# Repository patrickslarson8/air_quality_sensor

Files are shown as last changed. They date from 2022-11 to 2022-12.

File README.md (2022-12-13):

# Air Quality Sensor

A small air quality sensor that measures various 
aspects and logs them for later analysis.
Measures: VOC, C02, temperature, PM2.5, and humidity

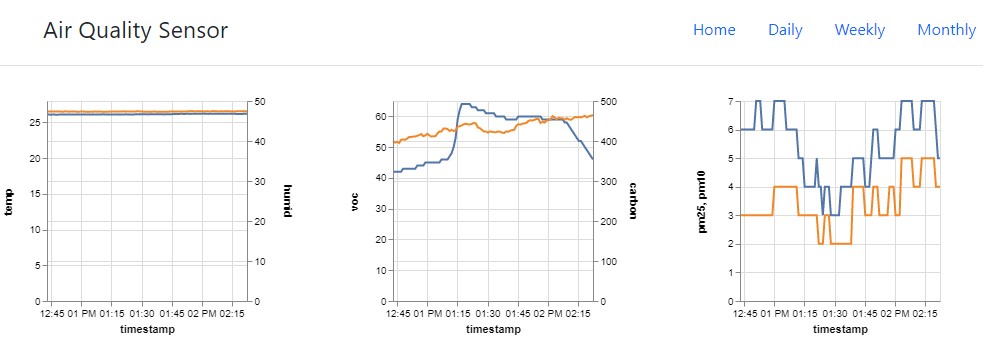
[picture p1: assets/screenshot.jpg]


## Hardware

Raspberry Pi
Adafruit SGP40 (https://learn.adafruit.com/adafruit-sgp40/python-circuitpython)  
Adafruit SCD-40 (https://learn.adafruit.com/adafruit-scd-40-and-scd-41/python-circuitpython)  
Adafruit PM 2.5 Sensor (https://learn.adafruit.com/pm25-air-quality-sensor)  

## How to use

### Wiring

- Notice that we are using the voltage regulator of the SGP40 to power the SCD40. This is because there is limited current supply from the Raspberry Pi and the RPi is notorious for weird bugs when underpowered.
- Additionally we need two wires that are split (purple and brown) so that both SGP40 & SCD40 can share the RPi i2c pins.
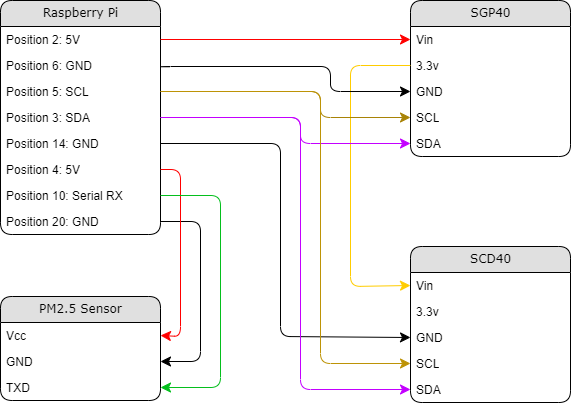
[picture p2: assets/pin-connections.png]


### Coding

1. Download repo

~~~bash
cd ~
git clone https://github.com/patrickslarson8/air_quality_sensor.git
~~~

2. Install requirements on system

~~~bash
cd air_quality_sensor
sudo apt-get install sqlite3 python3-pip libatlas-base-dev
~~~

3. Install python packages

~~~bash
sudo pip3 install -r requirements.txt
~~~

4. Create SQLite database

~~~bash
cd air-quality-service
sqlite3 database.db
sqlite> BEGIN;
sqlite> CREATE TABLE sensor_table (timestamp DATETIME, temp NUMERIC, humid NUMERIC, carbon NUMERIC, voc NUMERIC, pm10 NUMERIC, pm25 NUMERIC);
sqlite> CREATE TABLE note_table (timestamp DATETIME, note text);
sqlite> COMMIT;
~~~

5. Configure air_quality.py and webserver.py to autostart

- Open air_quality.service and web_server.service in a text editor and ensure the two locations for ExecStart point to your python interpretor and air_quality.py locations
- Copy air_quality.service to /lib/systemd/system/
- Add the correct permissions to the service file

~~~bash
sudo cp air_quality.service /lib/systemd/system/air_quality.service
sudo chmod 644 /lib/systemd/system/air_quality.service
sudo cp web_server.service /lib/systemd/system/web_server.service
sudo chmod 644 /lib/systemd/system/web_server.service
~~~

- Configure service to start

~~~bash
sudo systemctl daemon-reload
sudo systemctl enable air_quality.service
sudo systemctl enable web_server.service
sudo reboot
~~~

6. Schedule automatic reboot
~~~bash
sudo crontab -e
~~~
- Select the first option, nano
- Add the following at the end of the file
~~~bash
0 6 * * * /sbin/shutdown -r now
~~~
- Save the file by pressing ctrl+x then y

## Todo list

1. Add notes input to web page
2. Make air_quality service fault tolerant
  - Sensor Disconnect
  - Database non-existance
3. Fix time drift for polling (doesn't account for time taken to execute)

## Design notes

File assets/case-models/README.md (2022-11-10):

# Physical Enclosure Files

## How to use

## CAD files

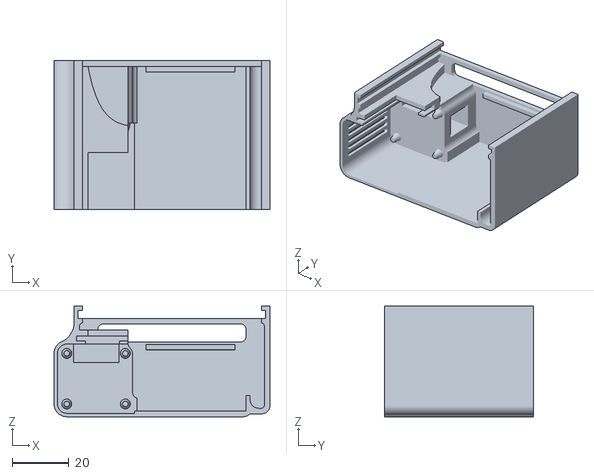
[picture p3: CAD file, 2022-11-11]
assets/case-models/Top Case.stl
76.0 x 52.3 x 38.9

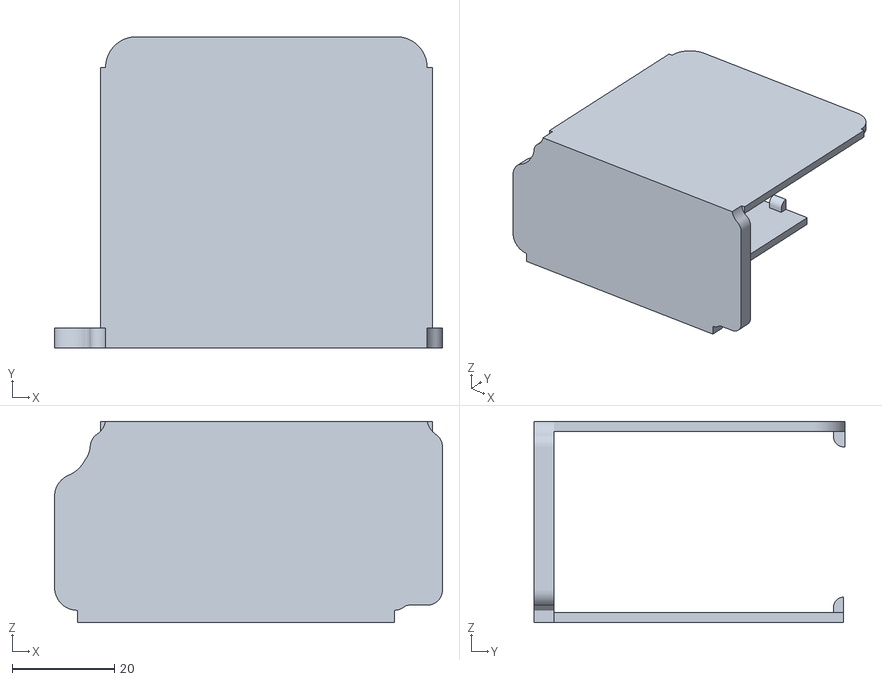
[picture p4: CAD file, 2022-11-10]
assets/case-models/Outer Lid.stl
76.0 x 61.0 x 39.4

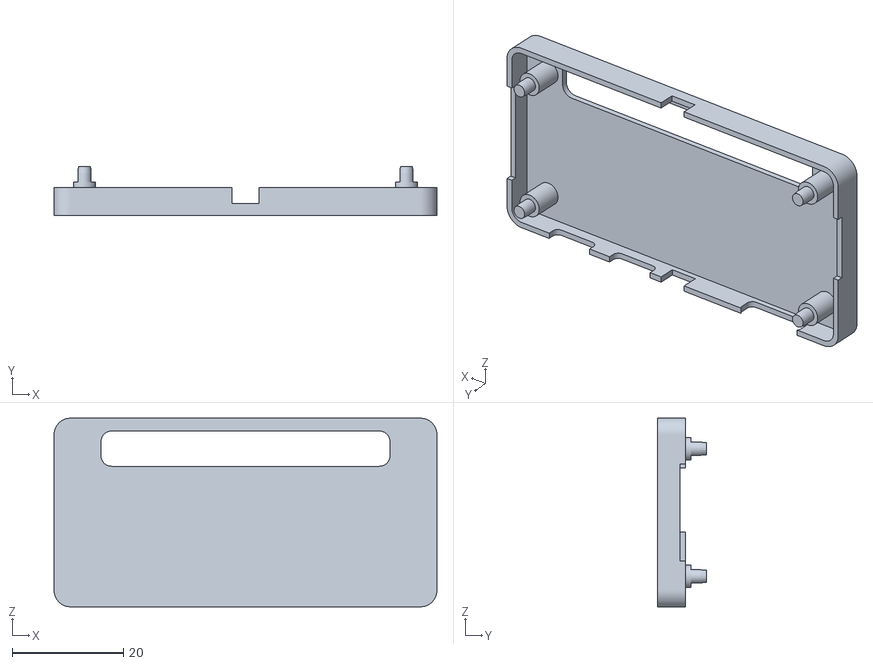
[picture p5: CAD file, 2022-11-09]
assets/case-models/Raspberry Zero 2W Case top.stl
69.0 x 8.75 x 34.0

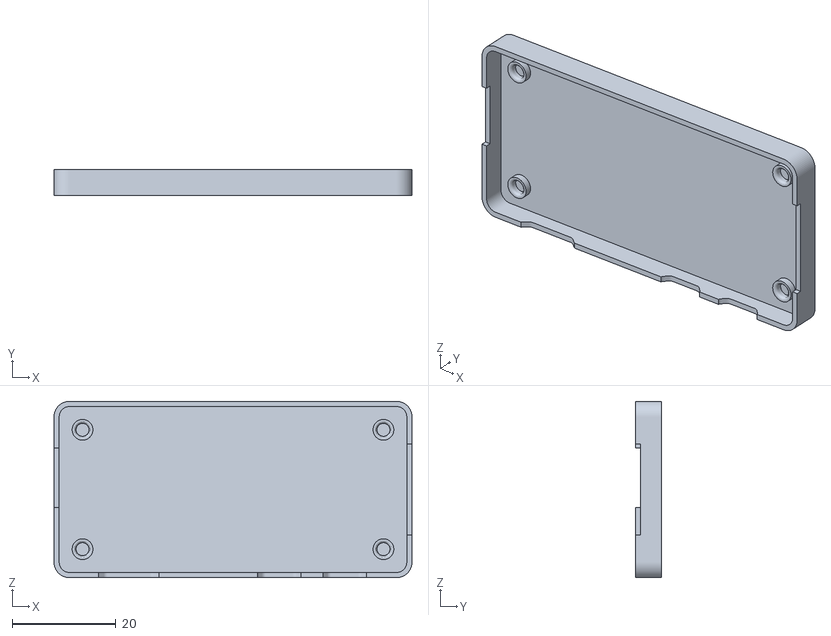
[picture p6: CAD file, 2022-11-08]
assets/case-models/Raspberry Zero 2W Case bottom.stl
69.0 x 5.00 x 34.0

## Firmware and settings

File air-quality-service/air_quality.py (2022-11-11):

# This script captures data from the sensors and logs it.
# TODO: add prep loop to stabilize voc algorithm before logging to database

import time
import board
import busio
import serial
import adafruit_sgp40
import adafruit_scd4x
from digitalio import DigitalInOut, Direction, Pull
from adafruit_pm25.uart import PM25_UART
import sqlite3 as lite
import sys

# Connect to local database
con = lite.connect('database.db')

# Set up IO
i2c = busio.I2C(board.SCL, board.SDA, frequency=100000)
uart = serial.Serial("/dev/ttyS0", baudrate=9600, timeout=0.25)

reset_pin = None


# Set up devices
# sgp
sgp = adafruit_sgp40.SGP40(i2c)

# scd
scd4x = adafruit_scd4x.SCD4X(i2c)
scd4x.start_periodic_measurement()

#pm25
pm25 = PM25_UART(uart, reset_pin)

# Set up object to save data
class airQuality:
  pm10 = 0
  pm25 = 0
  co2 = 0
  temp = 0
  humid = 0
  voc = 0


myAir = airQuality()


# Stabilize readings
print("Waiting for readings to stabilize")
time.sleep(180)  # pm25 requires 30 sec. SGP40 recommends several minutes before reading

# Read and log sensors
with con:
  cur = con.cursor()

time_polling_rate = 60
time_last_sgp_reading = time.time_ns()
time_last_gen_reading = time.time()

# Get temp and humid readings first to be used in VOC
myAir.temp = scd4x.temperature
myAir.humid = scd4x.relative_humidity

while True:
  # Read sensors
  
  # The SGP sensor algorithm is hardcoded and expects a 1 hz polling rate
  # If it hasn't been a second, sleep until it has been
  time_passed_sgp = time.time_ns() - time_last_sgp_reading
  if (time_passed_sgp < 1000000000):
    #update to nanoseconds
    time.sleep(1-(time_passed_sgp/1000000000))
  
  myAir.voc = sgp.measure_index(temperature=myAir.temp, relative_humidity=myAir.humid)
  time_last_sgp_reading = time.time_ns()
  
  time_passed_general = time.time() - time_last_gen_reading
  if (time_passed_general > 60):
    myAir.temp = scd4x.temperature
    myAir.humid = scd4x.relative_humidity
    myAir.co2 = scd4x.CO2
    aqdata = pm25.read()
    myAir.pm10 = aqdata["pm10 env"]
    myAir.pm25 = aqdata["pm25 env"]
    
    # log sensors
    # Table format is:
    # time, temp, humid, carbon, voc, pm10, pm25
    newEntry = "INSERT INTO sensor_table (timestamp, temp, humid, carbon, voc, pm10, pm25) VALUES (datetime('now'), {}, {}, {}, {}, {}, {});".format(myAir.temp, myAir.humid, myAir.co2, myAir.voc, myAir.pm10, myAir.pm25)
    #print(newEntry) 
    cur.execute(newEntry)
    con.commit()
    time_last_gen_reading = time.time()

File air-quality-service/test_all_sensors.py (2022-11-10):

import time
import board
import busio
import serial
import adafruit_sgp40
import adafruit_scd4x
from adafruit_pm25.uart import PM25_UART



# Set up IO
i2c = busio.I2C(board.SCL, board.SDA, frequency=100000)
uart = serial.Serial("/dev/ttyS0", baudrate=9600, timeout=0.25)

reset_pin = None

# Set up devices
# sgp
sgp = adafruit_sgp40.SGP40(i2c)

# scd
scd4x = adafruit_scd4x.SCD4X(i2c)
scd4x.start_periodic_measurement()

# pm25
pm25 = PM25_UART(uart, reset_pin)

time.sleep(33)

while True:
    # Read sensors
    # Get temp and humid readings first to be used in VOC
    temp = scd4x.temperature
    print("Temp: {}".format(temp))
    humid = scd4x.relative_humidity
    print("humid: {}".format(humid))
    print("CO2: {}".format(scd4x.CO2))
    print("VOC: {}".format(sgp.measure_index(temperature=temp, relative_humidity=humid)))
    aqdata = pm25.read()
    print("pm10: {}".format(aqdata["pm10 env"]))
    print("pm2.5: {}".format(aqdata["pm25 env"]))

    # Sleep for timing interval
    time.sleep(60)

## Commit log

2022-09-23 Update air_quality.py
    Add import libraries
    Add device set up
    Add main loop shell
2022-09-23 Update air_quality.py
    Add airQuality class to store data
    Add delay to for sensor stabilization
2022-09-29 Change PM2.5 sensor interface to serial
2022-10-01 Update air_quality.py
    Update PM25 for UART. Change reset pin to None. FIx typo assigning sgp object.
    [air_quality.py]
2022-10-01 Fix database entry string
    [air_quality.py]
2022-10-10 Update web_server.py to show current data (unformatted)
2022-10-15 Format information to print to web page
2022-10-21 Update web_server.py
    Add altair plot function for temperature
2022-10-21 Update altair to create temperature chart
2022-11-04 Add case and readme
    [rpi-zero-air-quality-case.f3d]
2022-11-06 Update case files
    [rpi-zero-air-quality-case.f3d]
2022-11-08 Trim cutout for QWIC connector
    [Outer Lid.stl, Raspberry Zero 2W Case bottom.stl, Raspberry Zero 2W Case top.stl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]
2022-11-08 Add pin diagram, delete unused files, update gitignore
2022-11-08 Reorganize folders
    [Outer Lid.stl, Raspberry Zero 2W Case bottom.stl, Raspberry Zero 2W Case top.stl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]
2022-11-08 Update README to show pin diagram
2022-11-08 Update case to better fit GPIO pins
    [Raspberry Zero 2W Case top.stl, Rpi Zero Air Quality Case v59.f3d, Rpi Zero Air Quality Case v61.f3d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]
2022-11-09 Update database schema
    [Outer Lid.stl, Raspberry Zero 2W Case top.stl, Rpi Zero Air Quality Case v61.f3d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]
2022-11-10 Update Outer Lid.stl, fix table name in air_quality.py
    [Outer Lid.stl]
2022-11-10 Delete Rpi Zero Air Quality Case v64.f3d
    Remove Fusion 360 project file
    [Rpi Zero Air Quality Case v64.f3d]
2022-11-11 Update air_quality.py to meet 1hz polling req of sgp40
    [Top Case.stl]
2022-11-11 Fix bug logging too much
    [air_quality.py]
2022-12-07 Add links to navbar buttons
